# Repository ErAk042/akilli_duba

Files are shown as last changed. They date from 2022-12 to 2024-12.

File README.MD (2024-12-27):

# Bu repository'de projemizin ilk versiyonu bulunmaktadır. Son hali için [-dosyalar daha yüklenmedi-]'i ziyaret edin.

# Akıllı Duba

Izmir Fen Lisesi öğrencileri tarafından 2204-A Lise Öğrencileri Araştırma Projeleri Yarışması için tasarlanan ve üretilen, içinde bulunduğu su ortamından
alg miktarı, iletkenlik, bulanıklık ve sıcaklık gibi parametrelerin ölçümünü yaparak bu verileri gsm aracılığı ile bir web veritabanına yükleyen duba.

## Genel Mekanik Yapı

Dubamızın ana gövdesi olarak elektronik sistemlerin içinde durduğu bir adet su geçirmez kutu kullanılmıştır. Fotodiyot ve LEDlerin bulunduğu optik sensör
bloğu kutunun içinde yer almaktadır. Bu seyede karanlık odanın mekanik yapısı daha basite indirgenebilmektedir ve su geçirmezlik açıısndan daha az muhtamel
hata noktası oluşmaktadır. Yapılacak ölçümlerin gün ışığından etkilenmemesi için kutunun içindeki bir servoya mıknatıslar ile bağlanan ve bu servo aracılığıyla döndürülerek örneğin gireceği delikleri açıp kapayan bir alt mekanizma tasarlandı. Bu sayede ölçümlerde gün ışığından gelen gürültü miktarının en aza indirilmesi amaçlanmıştır. 

## Optik ve Analog Kısım

Dubada, sudaki klrofil miktarı ölçümü için bir adet BPW34 fotodiyot kullanılmıştır. Bunun seçilmesinin temel sebeplerinden biri yüksek hassasiyete ve geiş bir ışığa duyarlı alana sahip olmasıdır. Bulanıklık sensöründe ise üstünde kızılötesi filtreleyen reçineden yapılma lens olması ve yüksek hassasiyet sebebiyle SFH 203-FA kullanılmıştır. Bu iki fotodiyodun da çıkışına sinyali yükseltme amaçlı düşük gürültülü sabit kazançlı(24x) ADPD2210 fotodiyot yükseltici entegresi kullanılmıştır. Bu fotodiyotlardan gelen sinyalleri arduinonun okuyabileceği bir dijital veriye çevirmesi için küçük ayak izine sahip ve I2C bus ile kolayca kullanılabilen ADS1115 analogtan dijitale çevirici entegresi kullanılmıştır. Sensörlerin durması gereken pozisyon neeniyle BPW34 ve ona ait yükseltici ayrı bir karta monte edilmiş ve bu kart ana karta bir adet 90° pin header ile bağlanmıştır. Ana kartta ayrıca kızılötesi fotodiyot için bir adet arduinonun dijital pinleri tarafından kontrol edilebilen mosfet ve bir sabit akım kaynağı kullanılmıştır. UV ledler için pilin gerilimi ile ledlerin çalışma gerilimi arasındaki yakınlık sebebiyle sadce arduinonun dijital pinleri ile açıp kapayabilmeyi sağlamak amacıyla bir mosfet konmuştur.

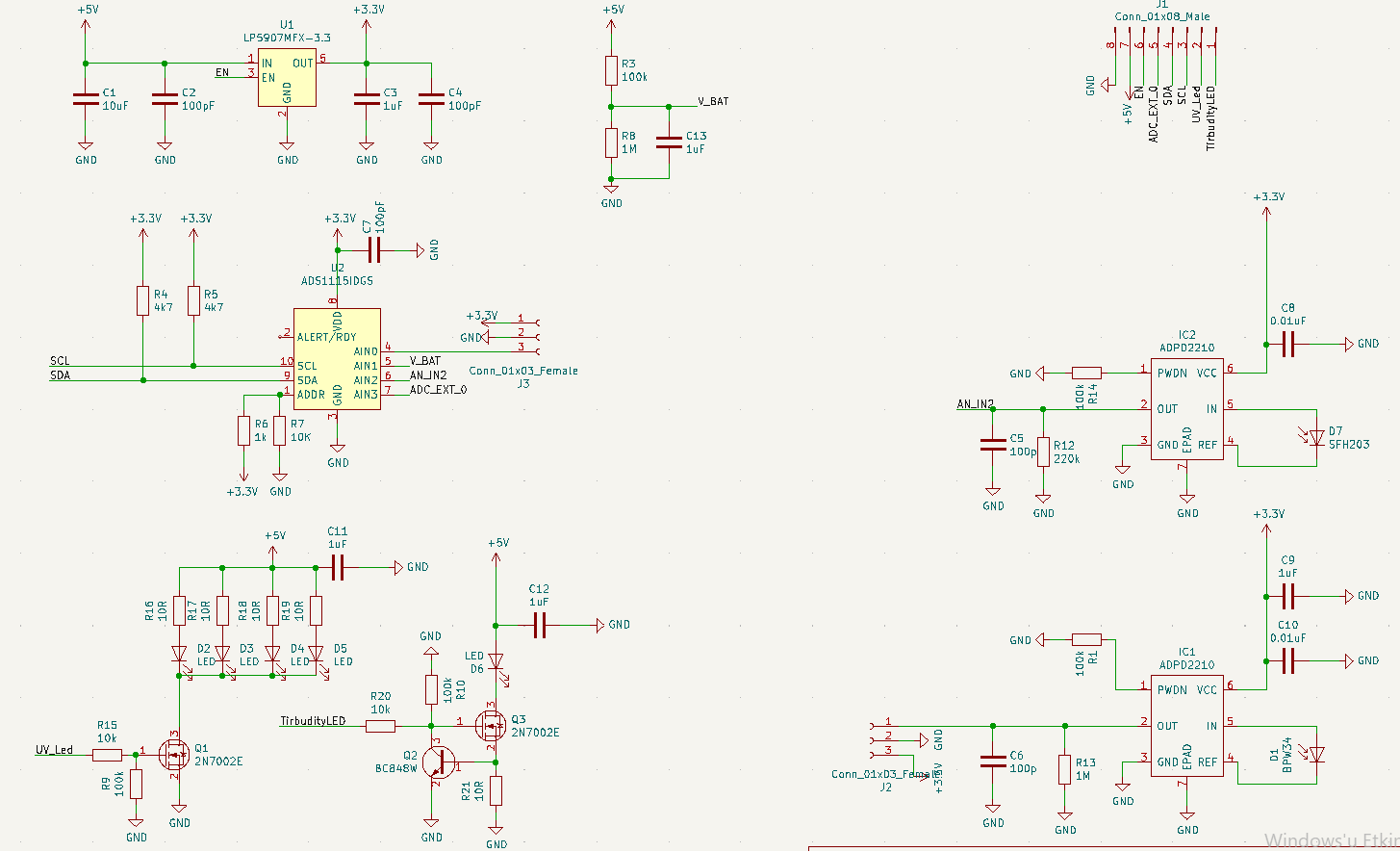
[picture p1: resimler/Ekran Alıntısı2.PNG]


Optik sensörler ve ADC yi içeren kartın şematiği

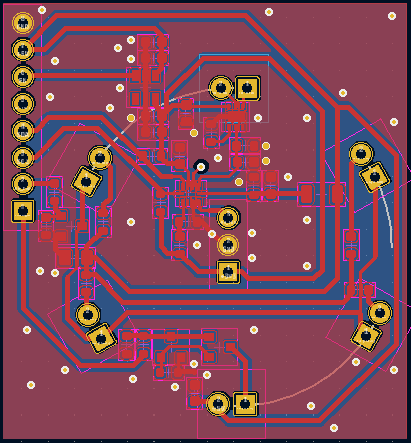
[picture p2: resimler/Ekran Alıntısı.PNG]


Optik sensörler ve ADC yi içeren kartın dağılım şeması

A

Hassas fotodiyot ve yükselticisini içeren kartın dağılım şeması

## İletkenlik Sensörü

Dubamız aynı zamanda suyun iletkenliğini ölçerek alg patlamalarının ana sebeplerden biri olan suya kirletici madde atılmasını tespit edebilmektedir. Bu ölçümü alırken sinyallerin su içinden geçerken ne kadar zayıfladığını ölçerek suyun ne düzeyde iletken olduğunu tespit eder. Bunu yaparken suyyun hidrolizini önlemek amacıyla suyun içinden CD4060 tarafından üretilen bir kare dalga geçirilerek bu durum önlenmektedir. Ardından bu kare dalga opamplar aracılığıyla doğrultularak Arduino tarafından analog olarak okunmaktadır. 

A

TDS sensör kartının şematiği

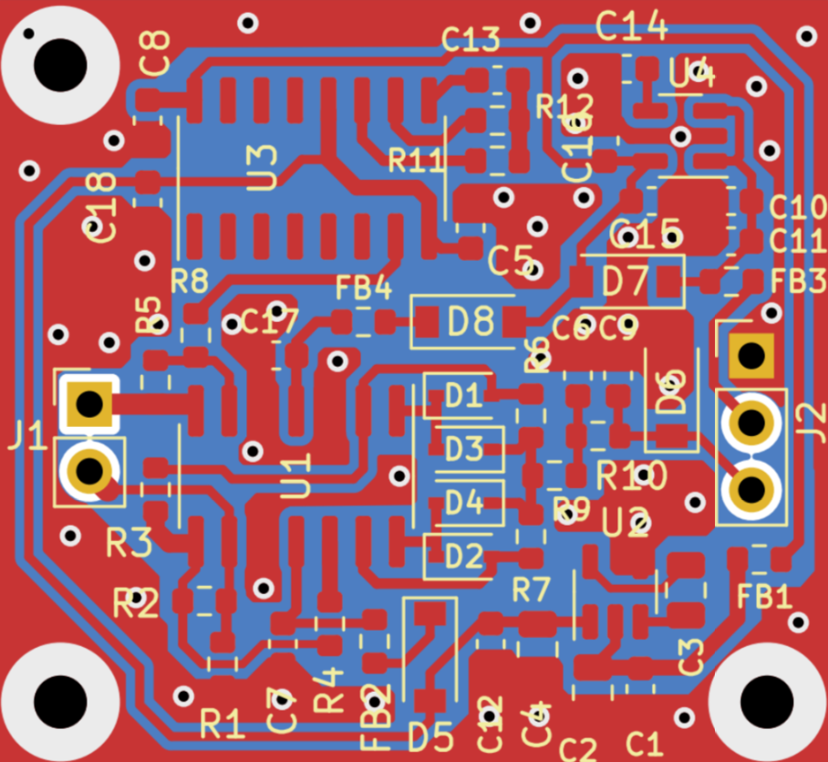
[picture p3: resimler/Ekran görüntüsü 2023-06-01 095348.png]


TDS sensör kartının dağılım şeması

------------------------------------------------------------------------------------------------------------------------------------------------------------------

# This repository contains the first prototype of our project. For the final version, please visit [-files yet to be uploaded-].

# Smart Buoy

Designed and produced by the students of Izmir Science High School for the 2204-A High School Students Research Projects Competition.
A buoy that measures parameters such as algae amount, conductivity, turbidity and temperature and uploads these data to a web database via gsm.

## General Mechanical Structure

As the main body of our buoy, a waterproof box was used in which the electronic systems are kept. Optical sensor with photodiodes and LEDs
block is located inside the box. This simplifies the mechanical structure of the darkroom and makes it less likely to be non watertight.
by reducing failure points from which water can get in. In order to prevent the measurements from being affected by daylight, a sub-mechanism was designed that is connected to a servo inside the box with magnets which are rotated by this servo to open and close the compartment where the sample will enter from. Whith this mechanism, our goal is to to minimize the amount of noise from daylight during measurements. 

## Optical and Analog Part

On the buoy, a BPW34 photodiode was used to measure the amount of chlorophyll in the water. This was chosen because it has high sensitivity and a large photosensitive area. For the turbidity sensor, SFH 203-FA was used due to its high sensitivity and the fact that it has a lens made out of infrared filtering resin. A low-noise fixed gain (24x) ADPD2210 photodiode amplifier ic was used to amplify the signal at the output of both photodiodes. In order to convert the signals from these photodiodes into digital data which the arduino can read, the ADS1115 analog-to-digital converter integration was used, which has a small footprint and can be easily used with the I2C bus. Due to the position where the sensors should be at, the BPW34 and its amplifier are mounted on a separate board and this board is connected to the main board with a 90° pin header. The main board also has a constant current source for the infrared photodiode and a mosfet which can be controlled by the digital pins of the arduino. For the UV LEDs, due to the proximity between the voltage of the battery and the operating voltage of the LEDs,only a mosfet was placed to enable on/off only with the digital pins of the arduino.

## Conductivity Sensor

Our buoy can also measure the conductivity of the water to detect contaminants in the water, one of the main causes of algae blooms. It does this by measuring how much the signal attenuates as it passes through the water to determine how conductive the water is. This is done by passing a square wave generated by CD4060 through the water to prevent hydrolysis of the water. This square wave is then rectified through opamps and read as analog value by Arduino.

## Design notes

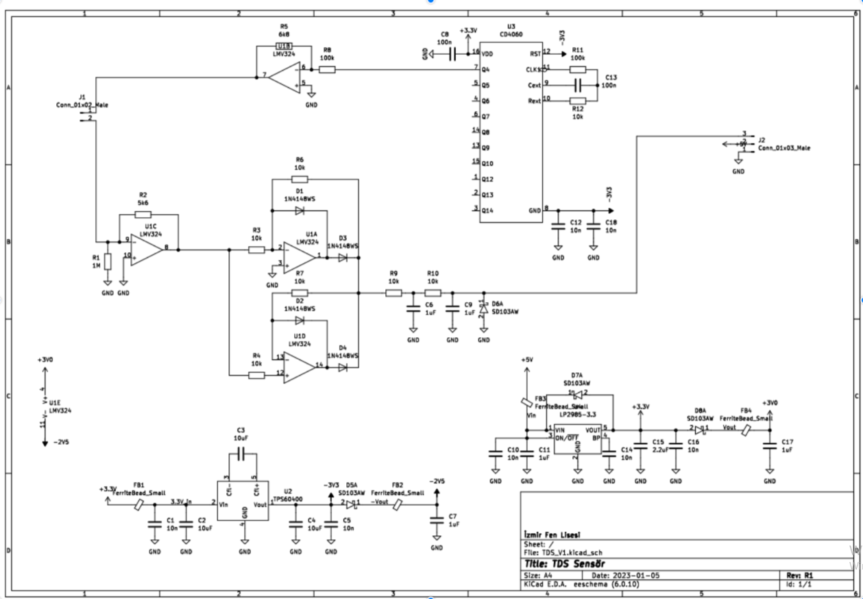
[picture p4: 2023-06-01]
resimler/Ekran görüntüsü 2023-06-01 094811.png

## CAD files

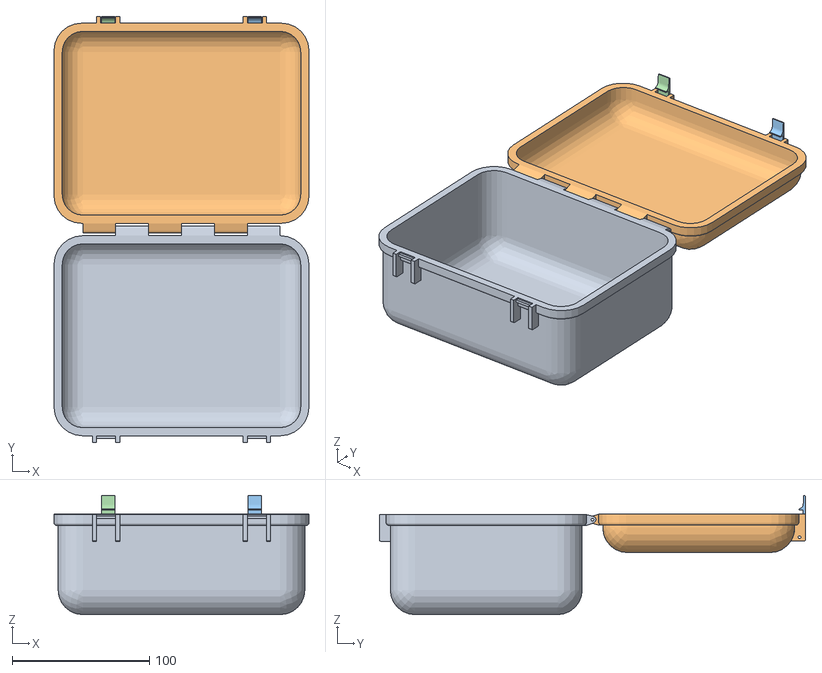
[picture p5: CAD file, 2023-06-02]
3d parcalar/duba kutu v3.obj
186.0 x 311.0 x 87.0

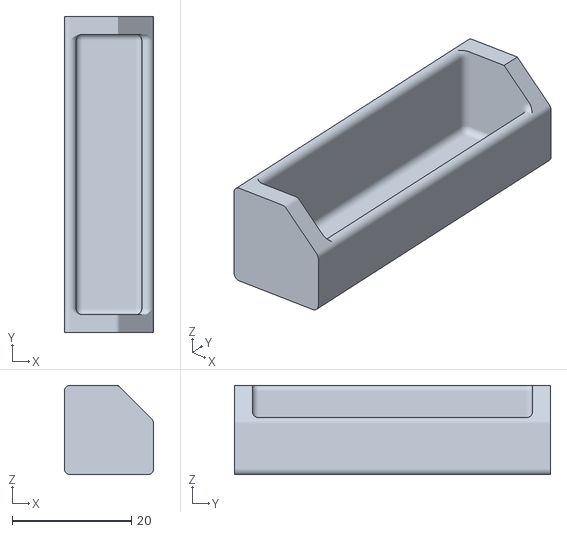
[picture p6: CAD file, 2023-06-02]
3d parcalar/ayak.obj
15.0 x 53.0 x 15.0

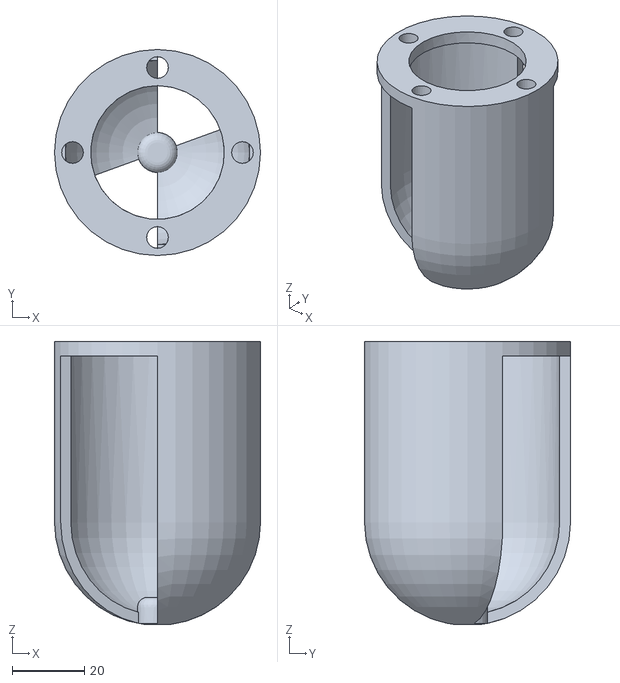
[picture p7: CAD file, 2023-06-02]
3d parcalar/duba alt ic v1.obj
57.0 x 57.0 x 78.3

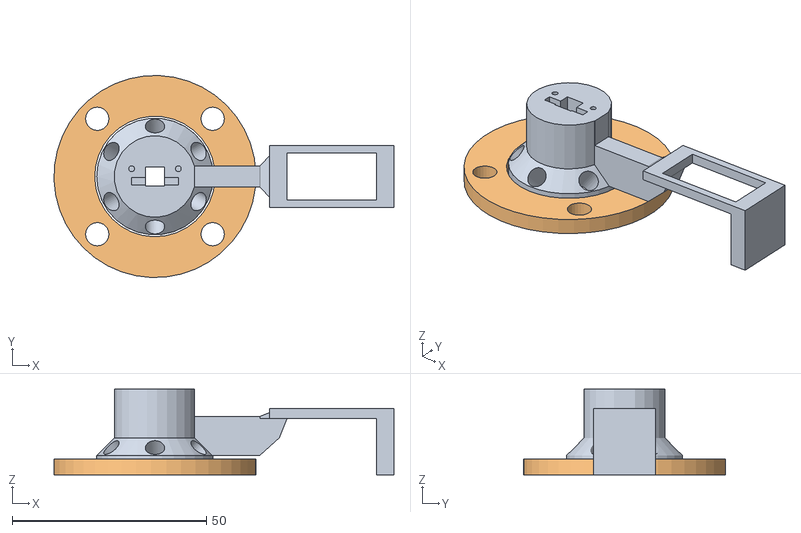
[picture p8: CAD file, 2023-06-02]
3d parcalar/duba sensor.obj
87.5 x 52.0 x 22.0

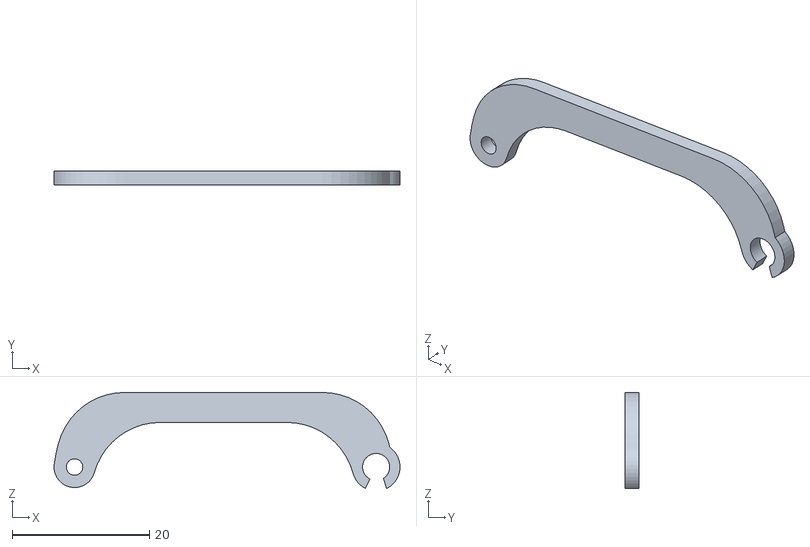
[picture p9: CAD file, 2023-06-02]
3d parcalar/YAMUK_KOL.obj
50.5 x 2.00 x 14.0

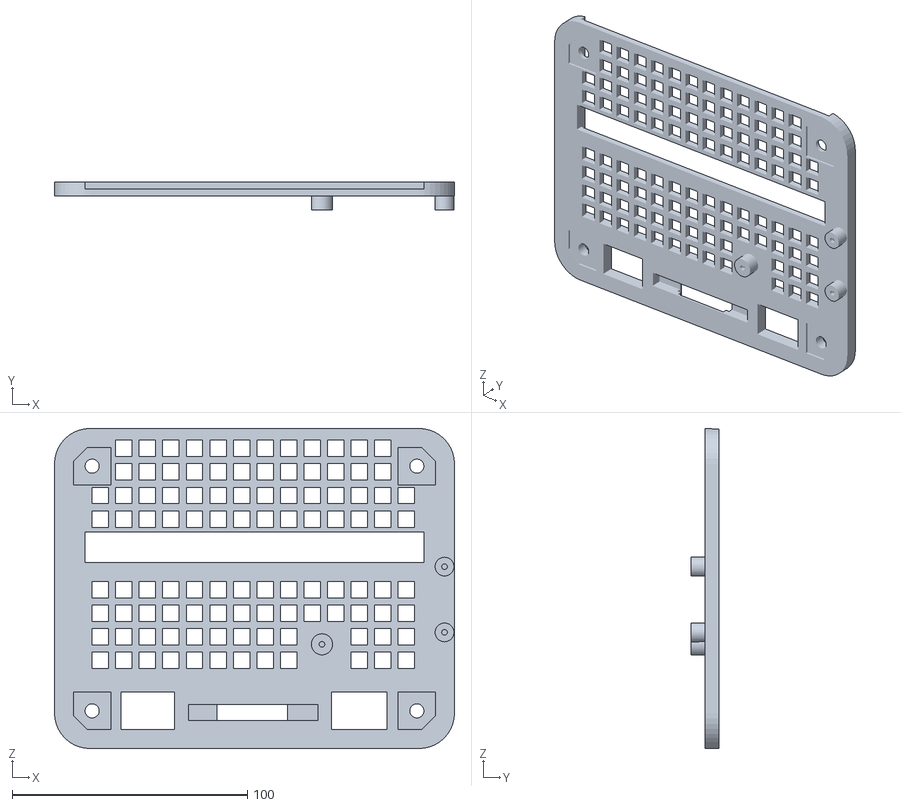
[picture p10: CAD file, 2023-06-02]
3d parcalar/kapak_2.obj
170.0 x 12.0 x 136.0

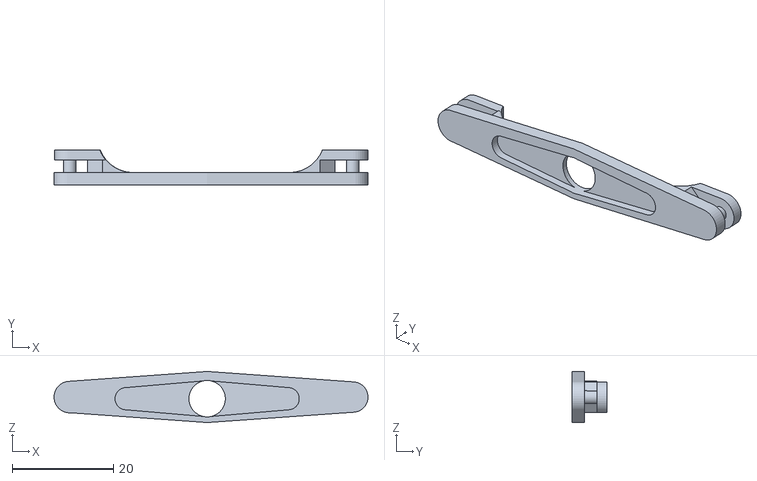
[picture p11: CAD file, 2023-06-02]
3d parcalar/servo_kol_1.obj
62.0 x 7.00 x 10.1

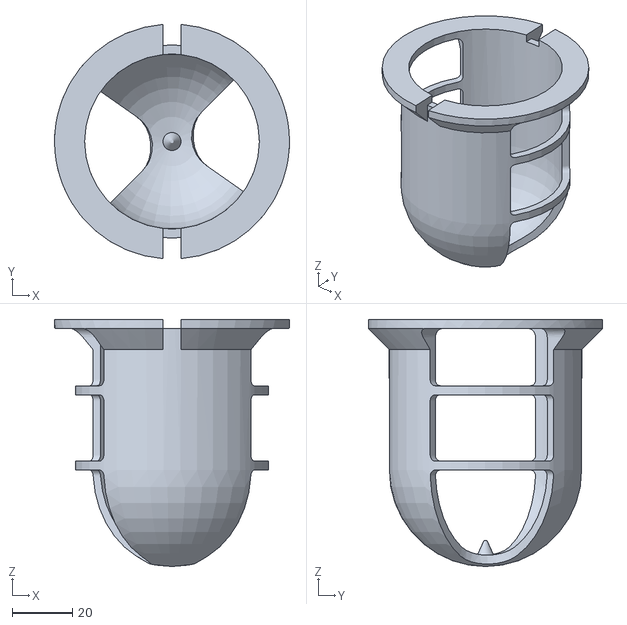
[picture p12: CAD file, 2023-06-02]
3d parcalar/duba alt dıs v2.obj
78.0 x 77.8 x 82.0

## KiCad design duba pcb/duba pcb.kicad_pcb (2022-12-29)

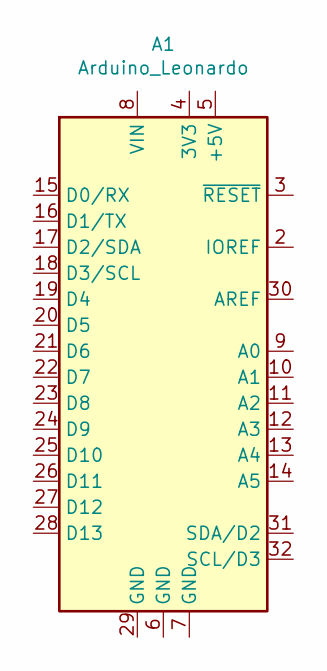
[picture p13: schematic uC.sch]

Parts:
A1: Arduino_Leonardo; Arduino_UNO_R3

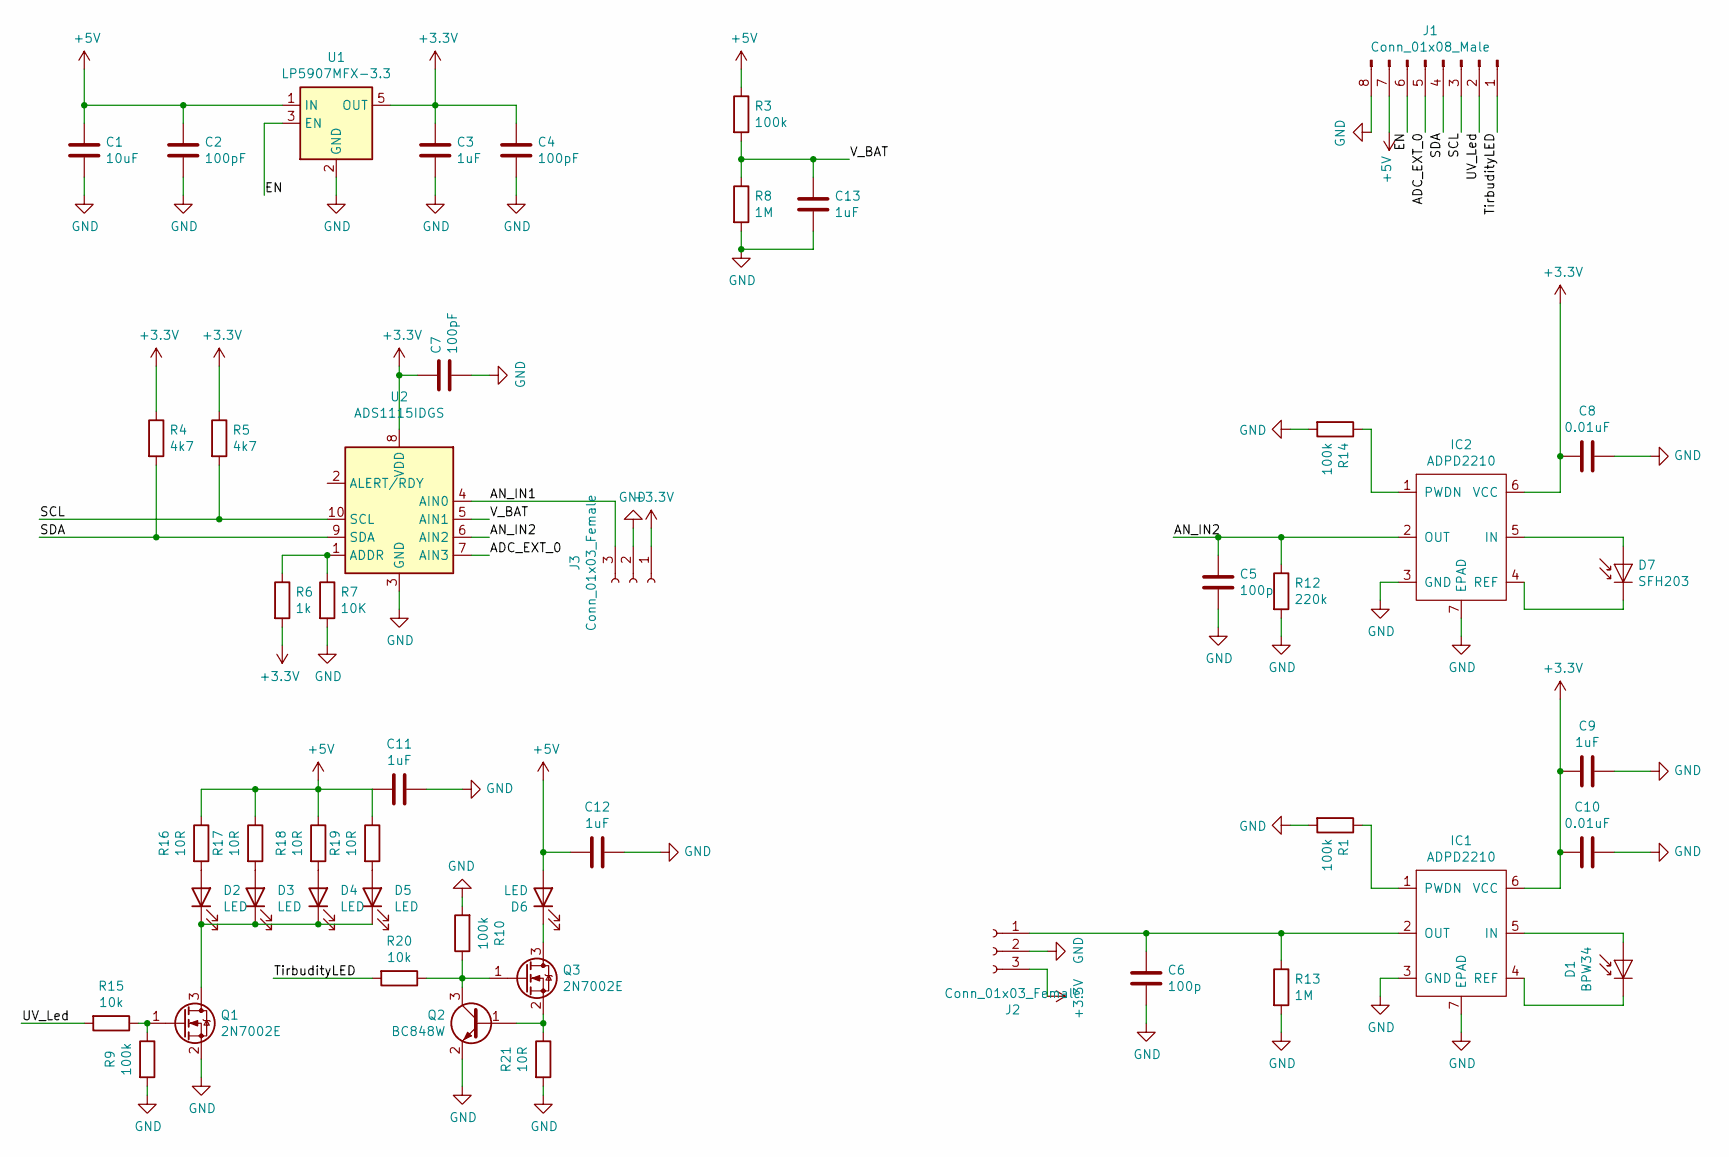
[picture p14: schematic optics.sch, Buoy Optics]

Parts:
C1: 10uF; C_0603_1608Metric
C2, C4, C7: 100pF; C_0603_1608Metric
C3, C9, C12, C13: 1uF; C_0603_1608Metric
C5, C6: 100p; C_0603_1608Metric
C8, C10: 0.01uF; C_0603_1608Metric
C11: 1uF; C_0805_2012Metric_Pad1.18x1.45mm_HandSolder
D1: BPW34; BPW34_SMD
D2, D3, D4, D5, D6: LED; LED_D5.0mm
D7: SFH203; LED_D5.0mm_IRGrey
IC1, IC2: ADPD2210; LFCSP-6
J1: Conn_01x08_Male; PinHeader_1x08_P2.54mm_Vertical
J2: Conn_01x03_Female; PinHeader_1x03_P2.54mm_Horizontal
J3: Conn_01x03_Female; PinHeader_1x03_P2.54mm_Vertical
Q1, Q3: 2N7002E; SOT-23
Q2: BC848W; SOT-23
R1, R9, R10, R14: 100k; R_0603_1608Metric
R3: 100k; R_1206_3216Metric
R4, R5: 4k7; R_0603_1608Metric
R6: 1k; R_0603_1608Metric
R7: 10K; R_0603_1608Metric
R8, R13: 1M; R_0603_1608Metric
R12: 220k; R_0603_1608Metric
R15, R20: 10k; R_0603_1608Metric
R16, R17, R18, R19, R21: 10R; R_0603_1608Metric
U1: LP5907MFX-3.3; SOT-23-5
U2: ADS1115IDGS; ADS1115_X2QFN

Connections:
+3V3: C3.1, C4.1, C7.1, C8.2, C9.2, C10.2, IC1.6 (VCC), IC2.6 (VCC), J2.3, J3.1, R4.1, R5.1, R6.2, U1.5 (OUT), U2.8 (VDD)
+5V: C1.1, C2.1, C11.2, C12.2, D6.2 (A), J1.7, R3.1, R16.1, R17.1, R18.1, R19.1, U1.1 (IN)
/optics/ADC_EXT_0: J1.5, U2.7 (AIN3)
/optics/AN_IN1: J3.3, U2.4 (AIN0)
/optics/AN_IN2: C5.1, IC2.2 (OUT), R12.1, U2.6 (AIN2)
/optics/EN: J1.6, U1.3 (EN)
/optics/SCL: J1.3, R5.2, U2.10 (SCL)
/optics/SDA: J1.4, R4.2, U2.9 (SDA)
/optics/TirbudityLED: J1.1, R20.2
/optics/UV_Led: J1.2, R15.2
/optics/V_BAT: C13.1, R3.2, R8.1, U2.5 (AIN1)
GND: C1.2, C2.2, C3.2, C4.2, C5.2, C6.2, C7.2, C8.1, C9.1, C10.1, C11.1, C12.1, C13.2, IC1.3 (GND), IC1.7 (EPAD), IC2.3 (GND), IC2.7 (EPAD), J1.8, J2.2, J3.2, Q1.2 (S), Q2.2 (E), R1.2, R7.2, R8.2, R9.2, R10.2, R12.2, R13.2, R14.2, R21.2, U1.2 (GND), U2.3 (GND)
unnamed: C6.1, IC1.2 (OUT), J2.1, R13.1
unnamed: D1.1 (K), IC1.4 (REF)
unnamed: D1.2 (A), IC1.5 (IN)
unnamed: D2.1 (K), D3.1 (K), D4.1 (K), D5.1 (K), Q1.3 (D)
unnamed: D2.2 (A), R16.2
unnamed: D3.2 (A), R17.2
unnamed: D4.2 (A), R18.2
unnamed: D5.2 (A), R19.2
unnamed: D6.1 (K), Q3.3 (D)
unnamed: D7.1 (K), IC2.4 (REF)
unnamed: D7.2 (A), IC2.5 (IN)
unnamed: IC1.1 (PWDN), R1.1
unnamed: IC2.1 (PWDN), R14.1
unnamed: Q1.1 (G), R9.1, R15.1
unnamed: Q2.1 (B), Q3.2 (S), R21.1
unnamed: Q2.3 (C), Q3.1 (G), R10.1, R20.1
unnamed: R6.1, R7.1, U2.1 (ADDR)

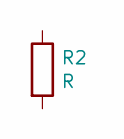
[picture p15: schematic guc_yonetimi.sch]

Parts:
R2: R; R_0603_1608Metric_Pad0.98x0.95mm_HandSolder

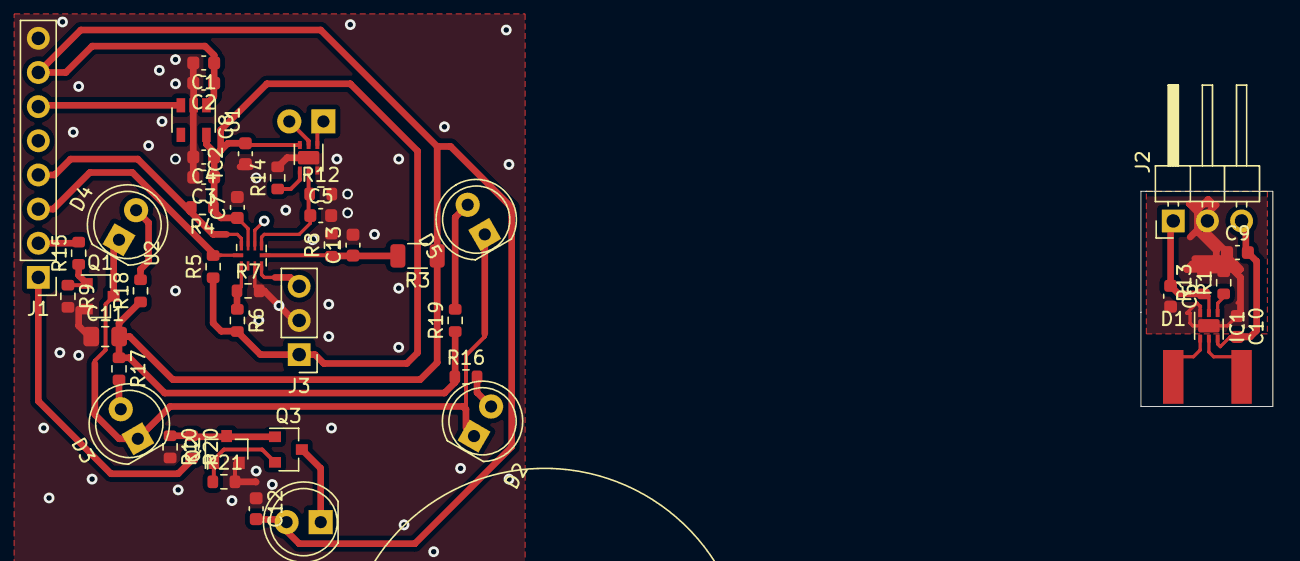
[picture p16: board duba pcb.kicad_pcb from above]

Board: 2 copper layers, 9.8 x 16.0 mm, 49 parts (1 on the bottom side), 29 nets.

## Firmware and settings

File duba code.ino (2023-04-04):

#include <Servo.h>
#include "Arduino.h"
#include "Wire.h"
#include "DHT.h"
#define I2Caddress 0x48
#define UVLED 8
#define IRLED 9
#define ISI A0
#define EN 7
#define DHTPIN 5   
#define SIM_EN 12
#define DHTTYPE DHT11 


String device_name = "Fenlisesi_Fake_Buoy2"; // Name your station
String dataout;


/*unsigned int readings[20] = {0};
unsigned char readCnt = 0;*/
Servo myServo;
DHT dht(DHTPIN, DHTTYPE);


//----------------------------------------------------------------------------------------------------**
//----------------------------------------------------------------------------------------------------**


void updateSerial()
{
  delay(20);
  while (Serial.available())
  {
    Serial1.write(Serial.read());//Forward what Serial received to Software Serial Port
  }
  while (Serial1.available())
  {
    Serial.write(Serial1.read());//Forward what Software Serial received to Serial Port
  }
}


void UplinkData(String dataName, String dataType, float dataval)
{
  Serial.flush(); // Make sure that serial is flushed

  Serial1.flush(); // Make sure software serial is flushed

  delay(2000);

  
  String json = "{\"key\":\"" + device_name + "\",\"measurement_name\":\"" + dataName + "\",\"unit\":\"" + dataType + "\",\"value\":" + String(dataval) + ",\"timestamp\":\""+ "1673818606" + "\",\"lat\":" + 70.0 + ",\"lon\":" + 30.0 + ",\"hardware\":\"None\"}";
  
  //  const char *fulljson = json.c_str(); // Because SoftwareSerial truncates pure strings, save json as a char

  // How many bytes the server should expect , how many seconds/1000 the server should wait for those bytes. Set to 120 bytes for now, trouble calculating sizeof(json)
  // Set to 89 if no date time
  // Set to 120 if date time
  Serial1.println("AT+HTTPDATA=" + String(json.length()) + ",10000");

  delay(2000);

  updateSerial();

  delay(2000);
  updateSerial();
  Serial1.println(json);
  delay(5000);
  updateSerial();
  Serial1.println("AT+HTTPACTION=1"); // 1 for post, 0 for get

  delay(5000);

  updateSerial();

  Serial1.println("AT+HTTPREAD"); // Read response
  
  delay(5000);

  updateSerial();

  delay(1000);

}


void intConnect()
{
  Serial1.println("AT"); //Once the handshake test is successful, it will back to OK

  updateSerial(); // Return the response to the serial port for display purposes, and print anything from either serial or SoftwareSerial. May be able to remove in actual deployment pending testing

  Serial1.println("AT+CSQ"); //Signal quality test, value range is 0-31 , 31 is the best

  delay(3000);

  updateSerial();

  Serial1.println("AT+CCID"); //Read SIM information to confirm whether the SIM is plugged in

  delay(1000);

  updateSerial();

  Serial1.println("AT+CREG?"); //Check whether it has registered in the network

  delay(1000);

  updateSerial();

  Serial1.println("AT+CGREG?"); // Check to see if the device is registered again

  delay(1000);

  updateSerial();

  Serial1.println("AT+COPS?"); // Returns the mobile network name i.e. T-mobile

  delay(1000);

  updateSerial();

  Serial1.println("AT+CGATT=1");

  delay(1000);

  updateSerial();

  Serial1.println("AT+CMGF=1"); // Set to SMS text mode

  delay(2000);

  updateSerial();

  Serial1.println("AT+SAPBR=3,1,Contype,GPRS"); // Set connection type to GPRS

  delay(2000);

  updateSerial();

  Serial1.println("AT+SAPBR=3,1,APN,internet"); // Change "internet" to the APN provided by your carrier

  delay(2000);

  updateSerial();

  Serial1.println("AT+CGACT=1,1"); // Perform GPRS attach, which must occur befpre PDP context can be established

  delay(2000);

  updateSerial();

  Serial1.println("AT+SAPBR=1,1"); // Enable bearer 1

  delay(5000);

  updateSerial();

  Serial1.println("AT+SAPBR=2,1"); // Check whether bearer 1 is open

  delay(3000);

  updateSerial();

  Serial1.println("AT+HTTPINIT"); // Initialize HTTP service

  delay(3000);

  updateSerial();

  Serial1.println("AT+HTTPPARA=CID,1"); // Set bearer profile ID

  delay(3000);

  updateSerial();

  Serial1.println("AT+HTTPPARA=URL,http://13.59.161.20:8080/api/v0p2/sensor"); // Server address

  delay(3000);

  updateSerial();

  Serial1.println("AT+HTTPPARA=\"CONTENT\",\"application/json\"");

  delay(2000);

  updateSerial();

  delay(1000);
}


//----------------------------------------------------------------------------------------------------**
//----------------------------------------------------------------------------------------------------**


float getHumidity()
{
  float val = dht.readHumidity();
  return val;
}


float getTemperature()
{
  float val = dht.readTemperature();
  return val;
}


void turnServo(int targetPos)
{
  // Turns the servo motor slover since fast movements cause magnets to decouple from each other. 
  // Attaches servo at the start and detaches at the end to avoid any excessive energy consumption.
  myServo.attach(10);
  int curPos = myServo.read();
  int diff = targetPos - curPos;
  int i;
  if (diff > 0)
  { 
    for (i = curPos; i <= targetPos; i += 1)
    {  
      myServo.write(i);             
      delay(15);
    }
  }
  else if (diff < 0)
  { 
    for (i = curPos; i >= targetPos; i -= 1)
    {  
      myServo.write(i);             
      delay(15);
    }
  }
  myServo.detach();
}


int readVal(int inpNo, int maxVolt, int SPS)
{
  // Start talking to ADS1115 
  Wire.beginTransmission(I2Caddress);
  Wire.write(0b00000001);
  int inpBit;
  int gainBit;
  int SPSBit;
  int MSB;
  int LSB;
  switch (inpNo)
  {
    // In order to manipulate MUX settings, you have to manipulate bits 14-12; in this case bits 6-4 of MSB. 
    // So we set a variable according to thoose bits and later, will att this to the MSB.
    case 0:
      inpBit = 64;
    break;
    case 1:
      inpBit = 80;
    break;
    case 2:
      inpBit = 96;
    break;
    case 3:
      inpBit = 112;
    break;
    default:
      inpBit = 64;
  }

  // In order to manipulate PGA settings, you have to manipulate bits 11-9; in this case bits 3-1 of MSB. 
  // So we set a variable according to thoose bits and later, will add this to the MSB.
  switch (maxVolt)
  {
    case 6144:
      gainBit = 0;
    break;
    case 4096:
      gainBit = 2;
    break;
    case 2048:
      gainBit = 4;
    break;
    case 1024:
      gainBit = 6;
    break;
    case 512:
      gainBit = 8;
    break;
    case 256:
      gainBit = 10;
    break;
    default:
      gainBit = 0;
  }

  // In order to manipulate PGA settings, you have to manipulate bits 7-5; in this case bits 7-5 of LSB. 
  // So we set a variable according to thoose bits and later, will add this to the LSB.
  switch (SPS)
  {
    case 8:
      SPSBit = 0;
    break;
    case 16:
      SPSBit = 32;
    break;
    case 32:
      SPSBit = 64;
    break;
    case 64:
      SPSBit = 96;
    break;
    case 128:
      SPSBit = 128;
    break;
    case 250:
      SPSBit = 160;
    break;
    case 475:
      SPSBit = 192;
    break;
    case 860:
      SPSBit = 224;
    break;
    default:
      SPSBit = 128;
  }

  // Finally adding all the choices into MSB and LSB. Since we are not going to use any other parameter other bits are not changeable.
  // In future use cases it might be possible to use other features like single-shot conversion or alert modes but in our case we don't use them.
  MSB = inpBit + gainBit;
  LSB = SPSBit + 3;
  
  Wire.write(MSB);
  Wire.write(LSB);

  Wire.endTransmission();

  Wire.beginTransmission(I2Caddress);

  Wire.write(0);

  Wire.endTransmission();

  // =======================================

  // Requesting the result from ADS1115
  Wire.requestFrom(I2Caddress, 2);

  uint16_t convertedValue;

  // Reading 2 bytes, then putting MSB in front of the LSB in order to get the 16-bit value. 
  convertedValue = (Wire.read() << 8 | Wire.read());
  // Converting the 16-bit value into voltage readings.
  int val = map(convertedValue, 0, 32767, 0, maxVolt);
  
  return val;
}


int getUV()
{
  int sonuc;
  sonuc = readVal(0,4096,128);
  Serial.println("UV olcumu yapılıyor.");
  turnServo(0);
  delay(1000);
  delay(100);
  digitalWrite(UVLED, HIGH);
  int i = 0;
  delay(50);
  /*for(i=0; i<=1000; i++)
  {
    sonuc = readVal(0,4096,128);
    Serial.println(sonuc);
    delay(20);
  }*/
  sonuc = readVal(0,4096,128);
  digitalWrite(UVLED, LOW);
  turnServo(75);
  return sonuc;
}


int getBattVoltage()
{
  readVal(1,4096,128);
  delay(50);
  int sonuc = readVal(1,4096,128);
  return 11*sonuc;
}


int getIR()
{
  int sonuc;
  sonuc = readVal(2,4096,128);
  Serial.println("IR olcumu yapılıyor.");
  turnServo(0);
  delay(200);
  digitalWrite(IRLED, HIGH);
  delay(500);
  sonuc = readVal(2,4096,128);
  delay(50);
  digitalWrite(IRLED, LOW);
  turnServo(75);
  return sonuc;
}


void setup()
{
  Serial.begin(9600);
  Serial1.begin(9600);
  pinMode(8, OUTPUT);
  pinMode(9, OUTPUT);
  pinMode(7, OUTPUT);
  pinMode(EN, OUTPUT);
  pinMode(SIM_EN, OUTPUT);
  digitalWrite(SIM_EN, LOW);
  digitalWrite(EN, HIGH);
  delay(5000);
  dht.begin();
  // Join the I2C bus as a master (call this only once)
  Wire.begin();

  turnServo(75);
  delay(200);
  Serial.println("Setup completed.");
  digitalWrite(UVLED, HIGH);
  delay(500);
  digitalWrite(UVLED, LOW);
}


void loop()
{
  
  Serial.println("w");
  delay(50);
  Serial.println("c");
  //digitalWrite(EN, HIGH);
  //delay(7000);
  Serial.println("d");
  int UVVoltage = getUV();
  delay(2000);
  Serial.println("e");
  int IRVoltage = getIR();
  delay(2000);
  int battVoltage = getBattVoltage();
  delay(500);
  int temp = getTemperature();
  delay(500);
  int hum = getHumidity();
  delay(500);
  //digitalWrite(EN, LOW);
  

  Serial1.println("AT+CFUN?");
  updateSerial();
  Serial1.println("AT+CFUN=1");
  updateSerial();
  //digitalWrite(SIM_EN, HIGH);
  delay(10000);
  intConnect();
  UplinkData("klorofil", "mV", UVVoltage);
  UplinkData("bulanıklık", "mV", IRVoltage);
  UplinkData("pil_voltaj", "mV", battVoltage);
  UplinkData("ısı", "°C", temp);
  UplinkData("nem", "%", hum);
  delay(1000);
  Serial.println("a");
  Serial1.println("AT+CFUN=0");
  updateSerial();
  Serial.println("b");
  //digitalWrite(SIM_EN, LOW);
  delay(3600000);
  
  /*int data;
  if (Serial.available() > 0) 
  {
    // read the incoming byte:
    data = Serial.read();
    
    switch(data)
    {
      case '0':
        Serial.println(getUV());
        delay(300);
      break;
      case '1':
        Serial.println(getBattVoltage());
      break;
      case '2':
        Serial.println(getIR());
        delay(300);
      break;
      case '3':
        Serial.println(getTemperature());
        Serial.println(getHumidity());
      break;
    }
  }*/

  //Serial.println(getUV());
  
}

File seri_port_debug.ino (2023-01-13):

#include <Servo.h>
#include "Arduino.h"
#include "Wire.h"
#define I2Caddress 0x48
#define UVLED 8
#define IRLED 9
#define ISI A0

unsigned int readings[20] = {0};
unsigned char readCnt = 0;
Servo myServo;


int isiOku()
{
  float sonuc;
  int olcum = analogRead(ISI);
  float voltage = olcum * (5000.0 / 1023.0);
  sonuc = (voltage-500)/10;
  return sonuc;
}


void servoCevir(int sonPos)
{
  myServo.attach(10);
  int konum = myServo.read();
  int fark = sonPos - konum;
  int i;
  if (fark > 0)
  { 
    for (i = konum; i <= sonPos; i += 1)
    {  
      myServo.write(i);             
      delay(30);
    }
  }
  else if (fark < 0)
  { 
    for (i = konum; i >= sonPos; i -= 1)
    {  
      myServo.write(i);             
      delay(30);
    }
  }
  myServo.detach();
}


int degerOku(int girisNo, int maxVolt, int ornekleme)
{
  Wire.beginTransmission(I2Caddress);
  Wire.write(0b00000001);
  int girisBit;
  int kazancBit;
  int SPSBit;
  int MSB;
  int LSB;
  switch (girisNo)
  {
    case 0:
      girisBit = 64;
    break;
    case 1:
      girisBit = 80;
    break;
    case 2:
      girisBit = 96;
    break;
    case 3:
      girisBit = 112;
    break;
    default:
      girisBit = 64;
  }

  switch (maxVolt)
  {
    case 6144:
      kazancBit = 0;
    break;
    case 4096:
      kazancBit = 2;
    break;
    case 2048:
      kazancBit = 4;
    break;
    case 1024:
      kazancBit = 6;
    break;
    case 512:
      kazancBit = 8;
    break;
    case 256:
      kazancBit = 10;
    break;
    default:
      kazancBit = 0;
  }

  switch (ornekleme)
  {
    case 8:
      SPSBit = 0;
    break;
    case 16:
      SPSBit = 32;
    break;
    case 32:
      SPSBit = 64;
    break;
    case 64:
      SPSBit = 96;
    break;
    case 128:
      SPSBit = 128;
    break;
    case 250:
      SPSBit = 160;
    break;
    case 475:
      SPSBit = 192;
    break;
    case 860:
      SPSBit = 224;
    break;
    default:
      SPSBit = 128;
  }

  MSB = girisBit + kazancBit;
  LSB = SPSBit + 3;
  Wire.write(MSB);
  Wire.write(LSB);
  Wire.endTransmission();
  //Serial.println(MSB);
  //Serial.println(LSB);
  Wire.beginTransmission(I2Caddress);

  Wire.write(0);

  Wire.endTransmission();

  // =======================================

  Wire.requestFrom(I2Caddress, 2);

  uint16_t convertedValue;

  convertedValue = (Wire.read() << 8 | Wire.read());
  int sonuc = map(convertedValue, 0, 32767, 0, maxVolt);
  
  return sonuc;
}


int UVOlcum()
{
  Serial.println("UV olcumu yapılıyor.");
  servoCevir(0);
  delay(1000);
  delay(100);
  digitalWrite(UVLED, HIGH);
  int i = 0;
  int sonuc;
  delay(50);
  /*for(i=0; i<=1000; i++)
  {
    sonuc = degerOku(0,4096,128);
    Serial.println(sonuc);
    delay(20);
  }*/
  sonuc = degerOku(0,4096,128);
  digitalWrite(UVLED, LOW);
  servoCevir(75);
  return sonuc;
}


int IROlcum()
{
  Serial.println("IR olcumu yapılıyor.");
  servoCevir(0);
  delay(200);
  digitalWrite(IRLED, HIGH);
  delay(500);
  int sonuc = degerOku(2,4096,128);
  delay(50);
  digitalWrite(IRLED, LOW);
  servoCevir(75);
  return sonuc;
}



void setup()
{
  Serial.begin(9600);
  pinMode(8, OUTPUT);
  pinMode(9, OUTPUT);

  // Join the I2C bus as a master (call this only once)
  Wire.begin();

  servoCevir(75);
  delay(200);
  Serial.println("Setup completed.");
  digitalWrite(UVLED, HIGH);
  delay(500);
  digitalWrite(UVLED, LOW);
}

void loop()
{
  int data;
  if (Serial.available() > 0) 
  {
    // read the incoming byte:
    data = Serial.read();
    
    switch(data)
    {
      case '0':
        Serial.println(UVOlcum());
        delay(300);
      break;
      case '1':
        Serial.println(degerOku(0,4096,128));
      break;
      case '2':
        Serial.println(IROlcum());
        delay(300);
      break;
      case '4':
        Serial.println(isiOku());
      break;
    }
  }

  //Serial.println(UVOlcum());

  
}

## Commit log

2022-12-29 PCBlerin çizimleri
    Sistemin analog kısmı ve ADS1115 ADC yi içeren kısmı
    [duba pcb.kicad_pcb, duba pcb.sch, guc_yonetimi.sch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]
2022-12-29 Sensör bloğu 3d çizimleri
    LED, fotodiyot ve sensör kartlarının bağlı olduğu plastık parçanın 3B çizimleri. 3B yazıcıdan bastırmaya uygun.
    [duba 2 v2.step, duba s v2.stl]
2023-01-02 dubanın ışığı bloke etme mekanizması
    [duba alt 2 v2.f3d]
2023-04-13 Rename duba 2 v2.step to sensor_blok
2023-06-02 Update sensor_blok

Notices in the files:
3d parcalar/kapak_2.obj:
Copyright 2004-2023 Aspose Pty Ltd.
